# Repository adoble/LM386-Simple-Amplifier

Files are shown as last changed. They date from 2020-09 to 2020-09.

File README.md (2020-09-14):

# LM386 Based Audio Stereo Amplifier

This is a simple LM386 based audio amplifier that I can use as a utility amplifier when dealing with audio signals. It is not really a "hifi" amplifier, but produces an acceptable sound on small loudspeakers.

The main purpose of the project though, was to do a [perfboard](https://en.wikipedia.org/wiki/Perfboard) design using [KiCad](https://kicad-pcb.org/). I've usually done the layout design in the past either with paper and pencil or even on the fly directly on the board. The results have not  been good.

## Circuit
The circuit is based strongly on the design shown in [Circuit Basics](https://www.circuitbasics.com/build-a-great-sounding-audio-amplifier-with-bass-boost-from-the-lm386/).

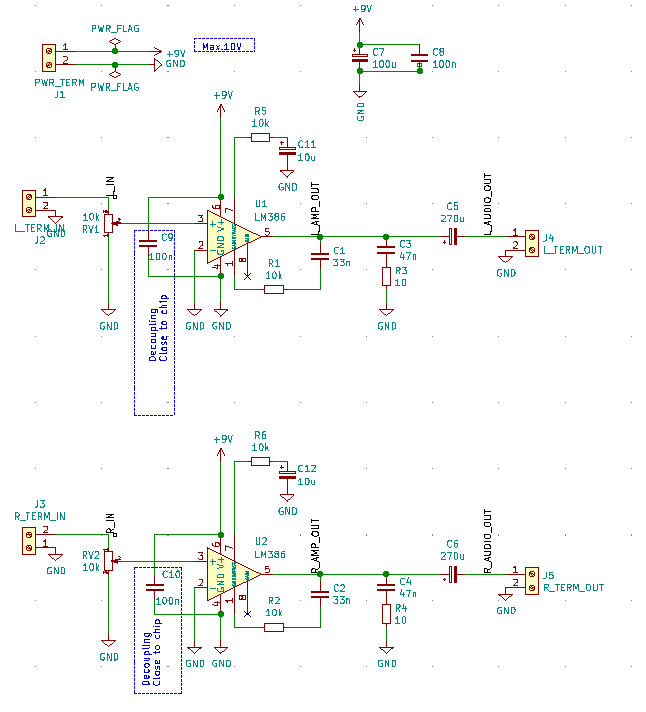
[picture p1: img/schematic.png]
Schematic


## Layout

One of the main reasons for this project was to see if KiCad could be used to layout the wiring on a perfboard, i.e. soldering bare wires on the back side of the perfboard. The result is shown below:

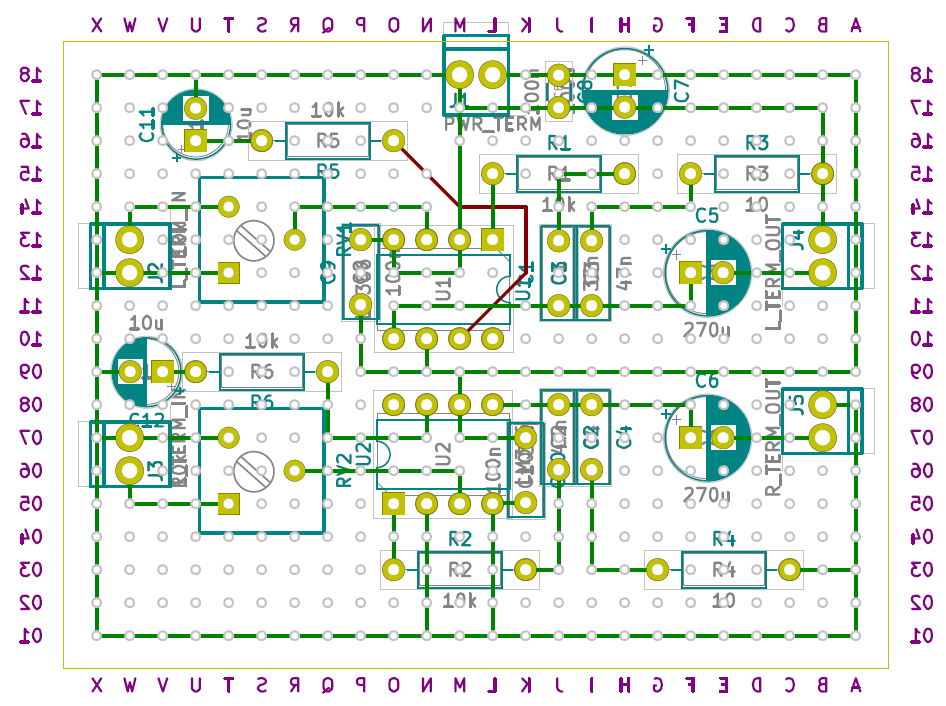
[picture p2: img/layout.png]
Layout


I set the grid to 2.54mm and then laid out the footprints. I then routed the pins together making sure that each track had only 90 degree turns. Finally I used to array layout function in KiCad to layout the vias. These represent the holes on the perfboard.  

I tried to get all components on the front side of the board with the connections as bare wires on the back side. Unfortunately I made a couple of changes after I had soldered some of the components and wiring, meaning a planar layout I had achieved before was no longer possible. You can see that with the one red (front side) track on the layout. I used an insulated wire, again on the back side, but put some isolation tape between it and the bare wires just to be sure.

Using the KiCad PCB tool meant it was a lot easier to do a clean(er) layout than when I used paper and pencil.

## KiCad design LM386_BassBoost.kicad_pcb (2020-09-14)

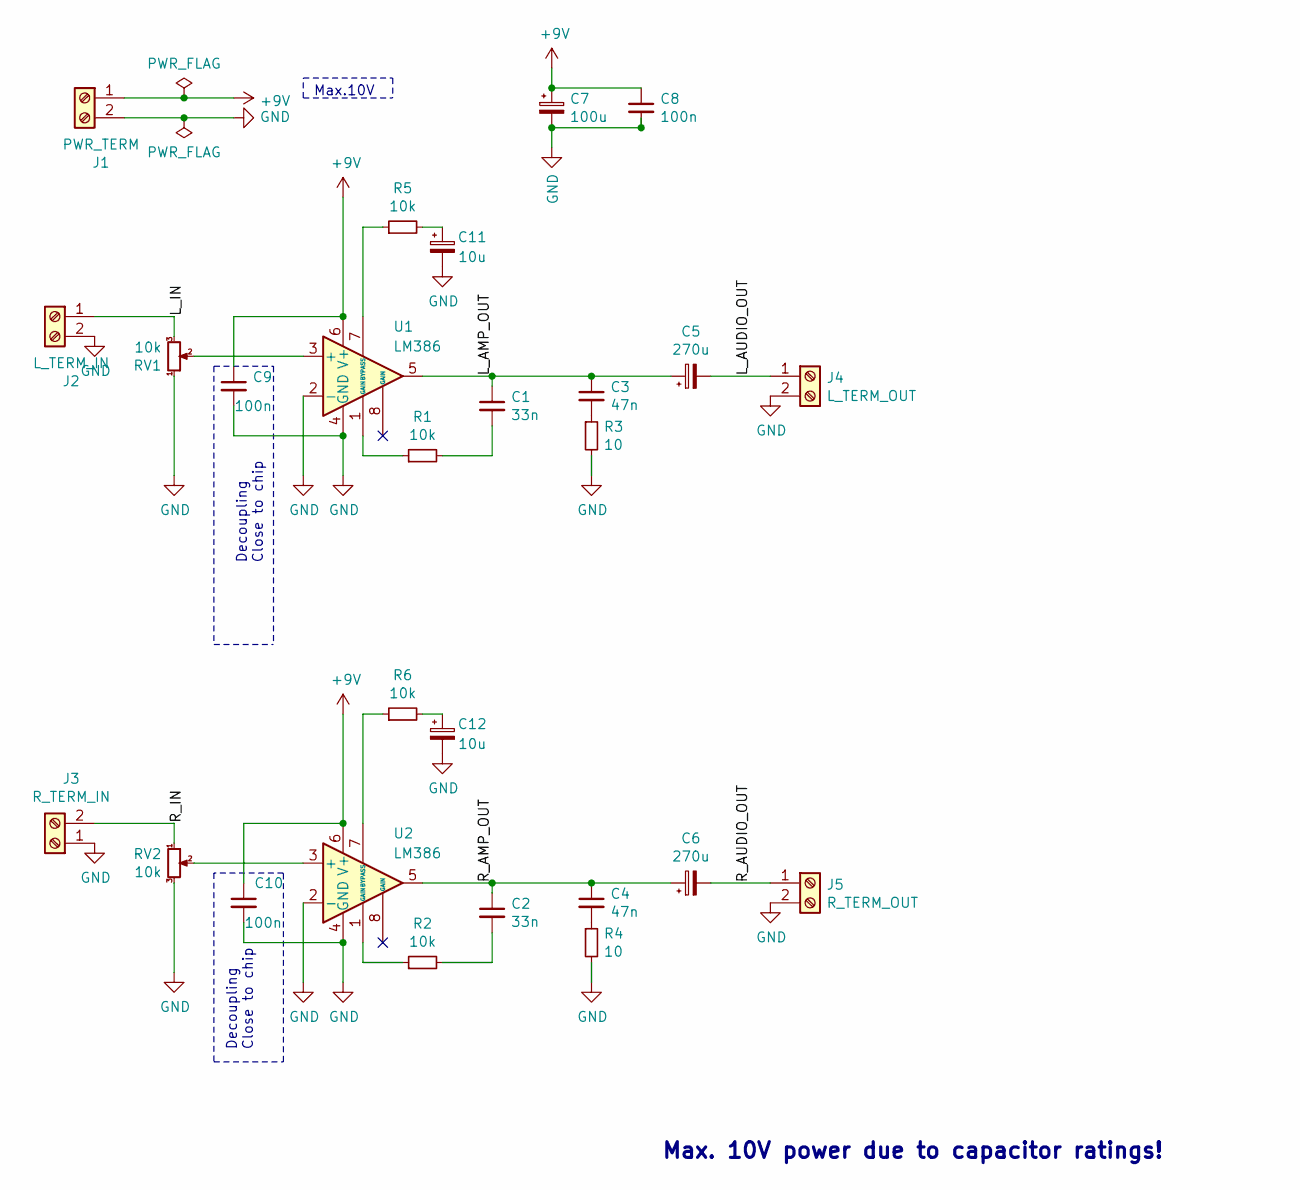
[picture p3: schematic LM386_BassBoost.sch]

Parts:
C1, C2: 33n; C_Disc_D7.0mm_W2.5mm_P5.00mm
C3, C4: 47n; C_Disc_D7.0mm_W2.5mm_P5.00mm
C5, C6: 270u; CP_Radial_D6.3mm_P2.50mm
C7: 100u; CP_Radial_D6.3mm_P2.50mm
C8: 100n; C_Disc_D3.0mm_W1.6mm_P2.50mm
C9, C10: 100n; C_Disc_D7.0mm_W2.5mm_P5.00mm
C11, C12: 10u; CP_Radial_D5.0mm_P2.50mm
J1: PWR_TERM; Screw_Terminal_1x02
J2: L_TERM_IN; Screw_Terminal_1x02
J3: R_TERM_IN; Screw_Terminal_1x02
J4: L_TERM_OUT; Screw_Terminal_1x02
J5: R_TERM_OUT; Screw_Terminal_1x02
R1, R2, R5, R6: 10k; R_Axial_DIN0207_L6.3mm_D2.5mm_P10.16mm_Horizontal
R3, R4: 10; R_Axial_DIN0207_L6.3mm_D2.5mm_P10.16mm_Horizontal
RV1, RV2: 10k; Potentiometer_Trimmer_Bourns_3310Y
U1, U2: LM386; DIP-8_W7.62mm

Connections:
+9V: C7.1, C8.1, C9.1, C10.1, J1.1, U1.6 (V+), U2.6 (V+)
/L_AMP_OUT: C1.1, C3.1, C5.1, U1.5
/L_AUDIO_OUT: C5.2, J4.1
/R_AMP_OUT: C2.1, C4.1, C6.1, U2.5
/R_AUDIO_OUT: C6.2, J5.1
GND: C7.2, C8.2, C9.2, C10.2, C11.2, C12.2, J1.2, J2.2, J3.1, J4.2, J5.2, R3.2, R4.2, RV1.1, RV2.3, U1.2 (-), U1.4 (GND), U2.2 (-), U2.4 (GND)
unnamed: C1.2, R1.2
unnamed: C2.2, R2.2
unnamed: C3.2, R3.1
unnamed: C4.2, R4.1
unnamed: C11.1, R5.2
unnamed: C12.1, R6.2
unnamed: J2.1, RV1.3
unnamed: J3.2, RV2.1
unnamed: R1.1, U1.1 (GAIN)
unnamed: R2.1, U2.1 (GAIN)
unnamed: R5.1, U1.7 (BYPASS)
unnamed: R6.1, U2.7 (BYPASS)
unnamed: RV1.2, U1.3 (+)
unnamed: RV2.2, U2.3 (+)

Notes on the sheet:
Max.10V
Max. 10V power due to capacitor ratings!
Decoupling Close to chip

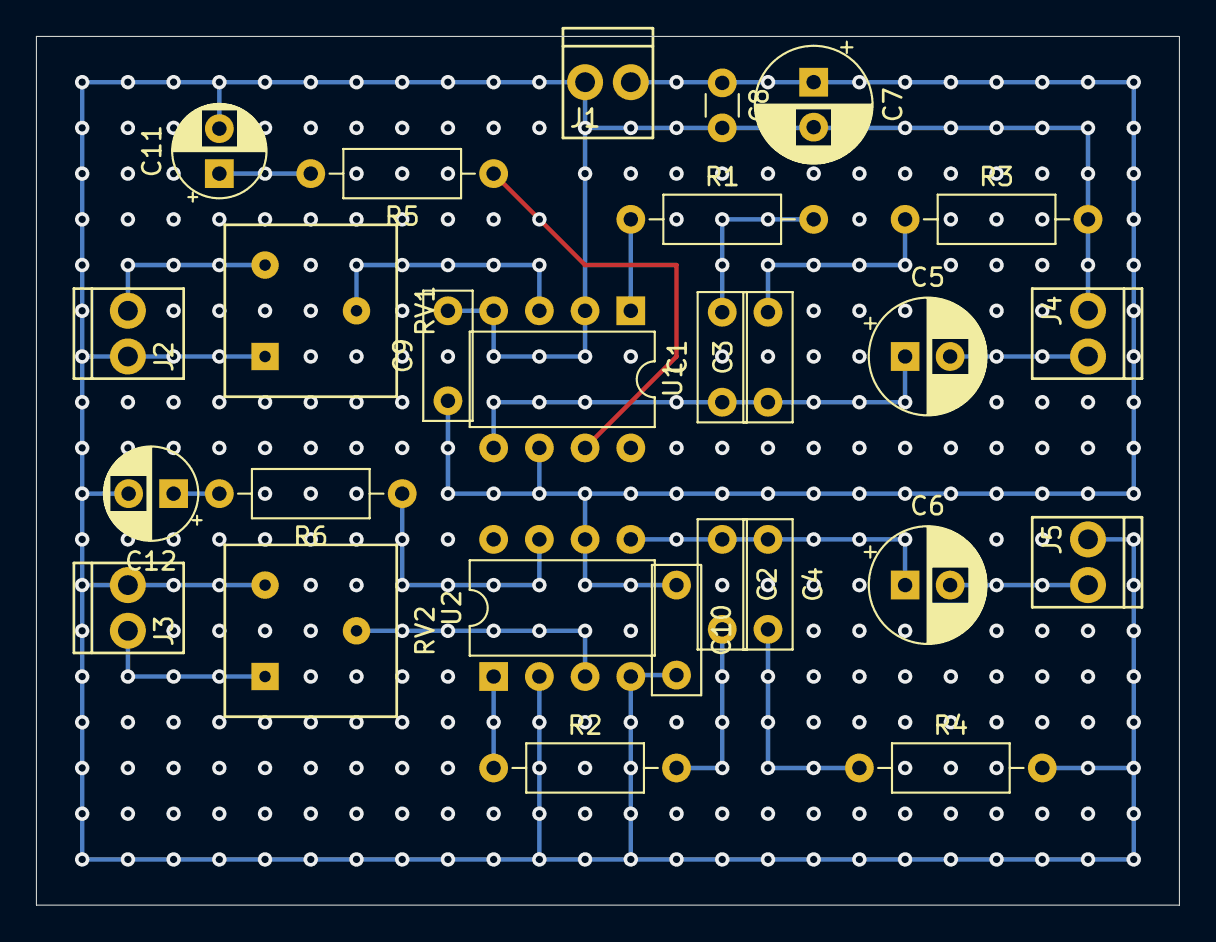
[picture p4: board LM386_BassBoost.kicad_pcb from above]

Board: 2 copper layers, 63.5 x 48.3 mm, 27 parts (0 on the bottom side), 20 nets.
